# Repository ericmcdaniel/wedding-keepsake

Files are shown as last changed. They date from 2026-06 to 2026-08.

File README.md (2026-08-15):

# Wedding Keychain Keepsake

This is the full schematic, design, plans, and source code for the interactive RGB LED keepsake gadget from Eric and Stephie's wedding on Saturday August 15th 2026. These PCBs are attached to a keychain and were distributed to guests as keepsake party favors. The keychain displays a bright grid of LED lights and features simple animations and games.

# Modes

When powered on, the keychain begins in either one of two modes: Animation mode and Game mode. Press and Hold the button for one second to switch between Animation and Game modes.

### Animation Mode

The keychain displays an animation from the selection below. Single-press the button to cycle between the following animations.
* Tunnel
* Swipe
* Rainbow
* American Flag
* Candle

### Game Mode

As of this writing, the keychain only offers one game named *Dodge*. Dodge is a space-themed endless runner arcade survival game. You are piloting a space shuttle, traveling through the solar system. You encouter space debris, and must evade them before they collide into you.

Single-press the button to steer your rocket in the opposite direction to dodge obstacles. Survive as long as you can, even as you accelerate through the debris at progressively faster rates.

# Bill of Materials

* 32 acrylic-diffused RGB LEDs, arranged in an 8x4 matrix.
* ~~A MEMS microphone and op-amp for simple audio sampling (no FFT).~~
  * This idea was included in the design and was manufactured. The idea was to create additional audio-reactive (and interactive) modes like animations for decibel and music analyzers, but development time exceeded my delivery timeline. This will be revisited later in future updates.
* Animations can be cycled and games that can be played using the single tactile push button.
* Controlled by the AVR-based ATtiny1614 manufactured by *Microchip Technology*.
* Powered by a 24mm x 5mm CR2450 coin cell battery.
* On an 80mm x 30mm PCB with a D-hook clasp and snake keychain.
* Placed inside a custom-made sled enclosure with snap-fit sliding lid.

# Design

## 3D Rendering
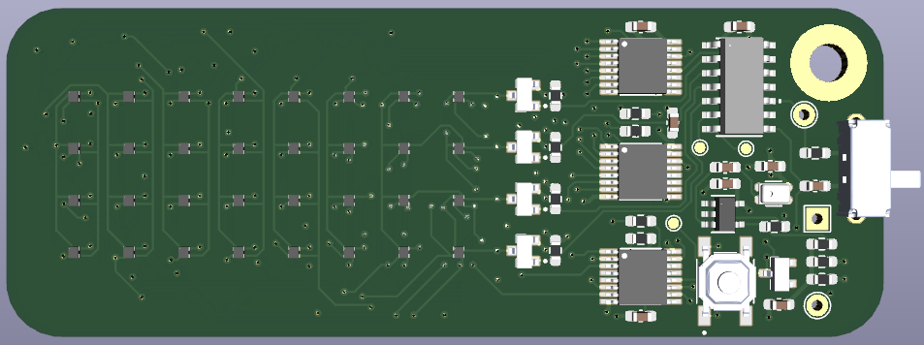
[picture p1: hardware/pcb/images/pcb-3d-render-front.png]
Front side of the PCB

<p align="center"><i>Front side of the PCB</i></p>

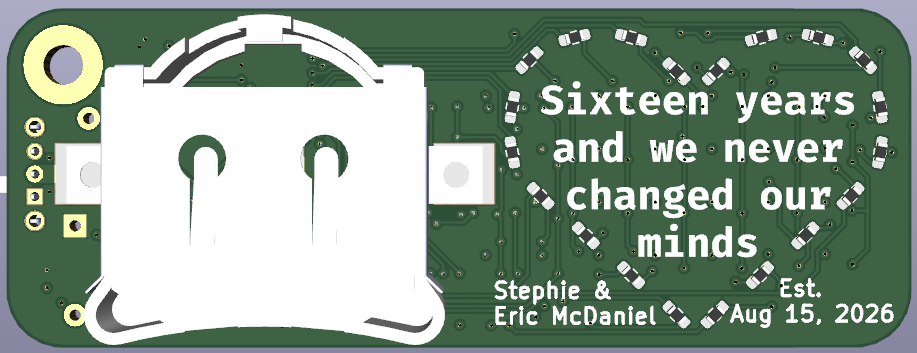
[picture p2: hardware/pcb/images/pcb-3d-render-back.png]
Back side of the PCB

<p align="center"><i>Back side of the PCB</i></p>

## Electrical Schematic
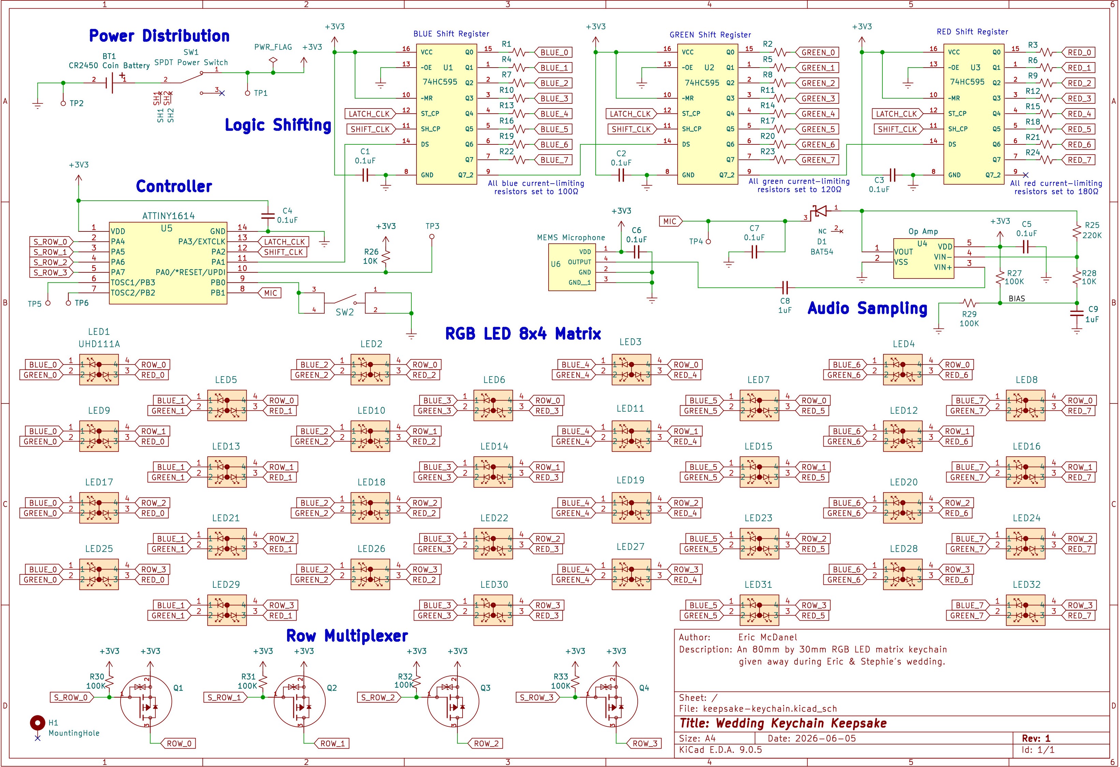
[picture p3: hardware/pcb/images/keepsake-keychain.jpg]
Electrical Schematic


## PCB Layout
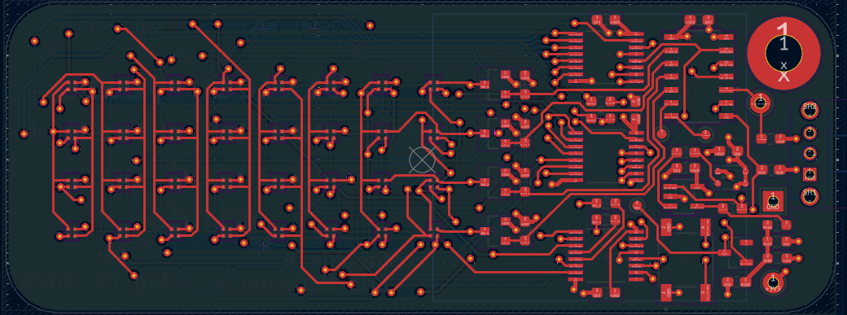
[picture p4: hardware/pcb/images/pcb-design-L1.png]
Layer 1 of PCB Design

<p align="center"><i>Layer 1 of the PCB (signals/components)</i></p>

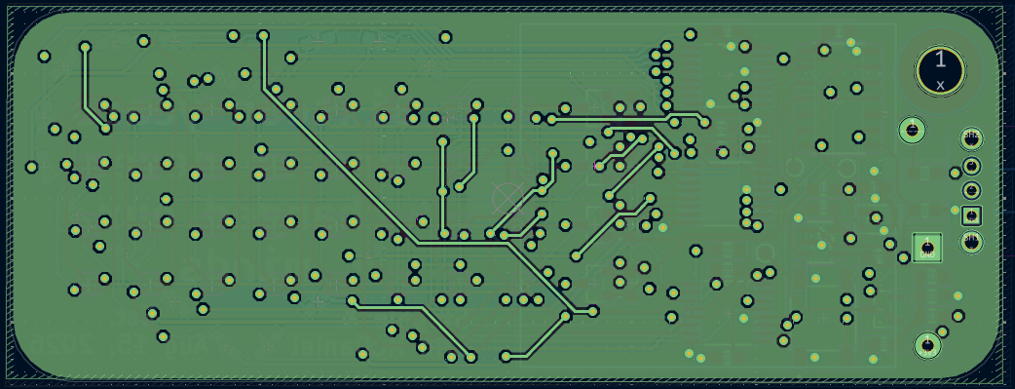
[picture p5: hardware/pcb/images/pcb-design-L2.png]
Layer 2 of PCB Design

<p align="center"><i>Layer 2 of the PCB (GND)</i><p>

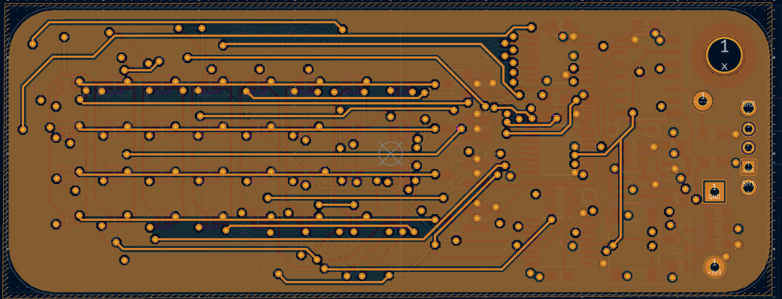
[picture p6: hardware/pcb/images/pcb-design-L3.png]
Layer 3 of PCB Design

<p align="center"><i>Layer 3 of the PCB (3V3 copper pour)</i><p>

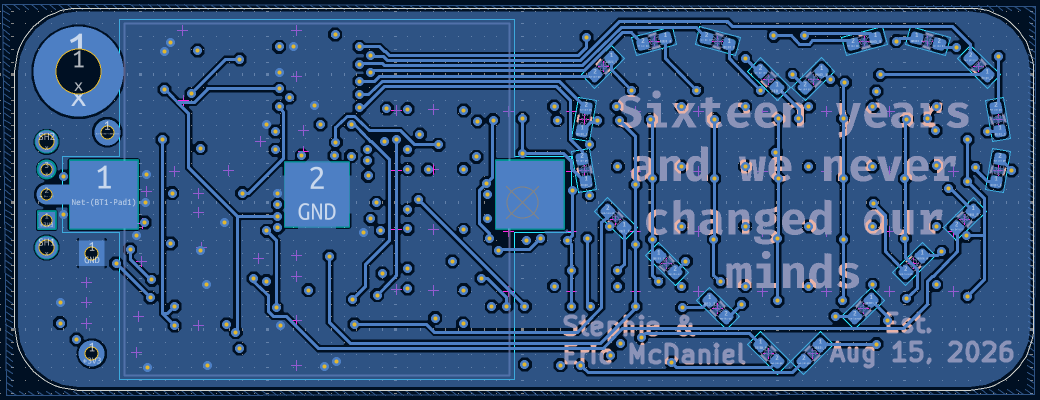
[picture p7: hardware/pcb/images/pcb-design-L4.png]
Layer 4 of PCB Design

<p align="center"><i>Layer 4 of the PCB (Additional signals/components)</i><p>

# Details

### Architecture and Engine

This repository was built using the toolkits provided by PlatformIO. It is based on the Arduino framework, though quite minimally. An RTOS is not used, fairly bare metal in terms of architecture. To keep things as efficient as possible, abstractions that Arduino provides like `digitalWrite()` were replaced with direct register manipulations, especially duirng hot execution paths. Most notably it is used during the LED rendering logic, which renders each row sequentially for 50 microseconds, creating a multiplexed effect on the display, as if all the LEDs were on simutaneously. The main reason that the Arduino framework is still used is because of the timers.

Internally, this repo was built on top of the custom game engine used in the [LumenLab](https://github.com/ericmcdaniel/lumenlab), with a handful of adaptations. This includes the platform-level core services, the engine, and general architecture from the LumenLab. This repo implements multiplexing manually, so libraries like FastLED used in the LumenLab could not be used. The keychain runs the main game loop at 60 Hz. Between each frame, the engine multiplexes each row at a frequency of 20 kHz (50 microseconds). Between each row rendering, three shift registers designated to the red, green, and blue channels take in a serial stream of bits to indicate if the respective color's LED should be on. If it's signal LOW, the LED turns on, and if signal HIGH then off. (this is in reverse because the MOSFETS are active HIGH).

Pulse-width modulation (PWM) is needed to dim the three primary colors, allowing for any arbitrary color can be made via blending. This was implemented using [bit-angle modulation (BAM)](https://www.desertember.com/posts/bit-angle-modulation.html) to determine the duty cycle. That was a headache, almost literally, because given large time values, the PWM's duty cycle would be so spread your eyes would noticably see the flicker. The color depth was reduced to 6-bit. The flicker isn't fully removed, but it's significantly better. Brightness and gamma correction was implemented, but disabled because adjustmenets is needed (again, mostly due to the noticable PWM flicker).

### Audio profiling (not implemented)

A MEMS microphone and amplifier was a part of the keychain's goal and is still a part of the design and schematic. The idea was realistic to implement, but was bound by an ambitious timeline, so I had to pause development that for now. The microphone still remains on the PCB since they were already manufactured (center-right). This gives me the opportunity to simply suspend working on the audio-reactive features rather than cancel entirely.

The idea for this keychain was to include audio reactivity, which would complement the already interactive animations. Running a full spectrum analyzer was not possible given the microcontroller selected, power constraints, and technical limitations like the inability to timely perform computationally heavy Fast-Fourier Transformations (FFT). So to be clear, it is too low-powered/low-budget to record conversation. Instead, the device was going to sample decibel levels in real time and display a sound-reactive bar, like the EQ on a stereo system. Another idea I had for the built-in microphone was to make the devices react to the wedding reception music live in real time. Between songs, I could have my computer play a swift, 20+ kHz logic signal at the before every song. This high-frequency chirp wouldn't be heard by humans, but detected by this keychain. It would then decode the message, and play an animation or color theme dynamically, as if it's listening to the music and dancing along.

These were two ideas that have artifacts on the board, but were not implemented.

# Development

### Software

The keychain is programmable using the UPDI protocol, which is the newer version of AVR's ISP and JTAG programming. The UPDI (PA0, pin 10) is exposed on a THT test pad, along with 3V3 and GND. To program the device, you need a $7 module called the UPDI Friend - USB Serial UPDI Programmer from [Adafruit](https://www.adafruit.com/product/5879) or [Digikey](https://www.digikey.com/en/products/detail/adafruit-industries-llc/5879/22596413). Releases are provided every PR and can be flashed directly. I'll write instructions to directly flash the device later (hopefully), and possibly even dockerize it for simplicity. Until then, the easiest way to update is to install the PlatformIO toolkit, compile this repo locally, and flash using the *PlatformIO: Upload (Release)* build script included.

In addition to the UPDI pin, PB2 (pin 7) and PB3 (pin 6) are mapped to TX and RX respectively. Because they were unused, these pins are exposed as SMD test pads. This allows you to probe TX (PB2) to read the serial logs, if you compiled the debug version.

### Hardware

The PCB design files were made using KiCad 9.0.5. The board layout was optimized for the manufacturing capabilities of [PCBWay](https://www.pcbway.com/). Before you start writing me hate mail, know that I'm aware of the issues, such as the lack of ESD protection and reverse polarity protection. Perhaps a future revision can include these, but I have no such plans.

The enclosure was made using FreeCAD 1.1.0. They also suck, but I tried. The models were also exported as .3mf files, and were optimized for immediate FDM printing, particularly the Bambu Labs A1 Combo. Feel free to adjust as needed for your machine. The model includes a sled enclosure which retains the PCB using four friction fit ribs. A lid is attached by sliding it along the guide rails from left to right. A snap-fit latch locks the lid in place, preventing it from falling off. I printed this using Bambu Lab's PLA Basic, however given the variance between 3D printers, brands, filament, and other conditions, your mileage may vary.

## AI Disclaimer

AI was consulted as a research and discovery analysis tool. I asked it general design, architecture, and best practices questions, especially during the board bring-up stage. I don't have a professional background in electrical engineering (is YouTube University accredited?), so I used it as a an informational resource. 

*Generative* AI, however, was **not** used to author code. Call me a luddite, but this is out of priniciple. Software engineering is an art as it is a science. Cheers to all the other crazies out there!

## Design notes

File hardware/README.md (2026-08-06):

# Enclosure

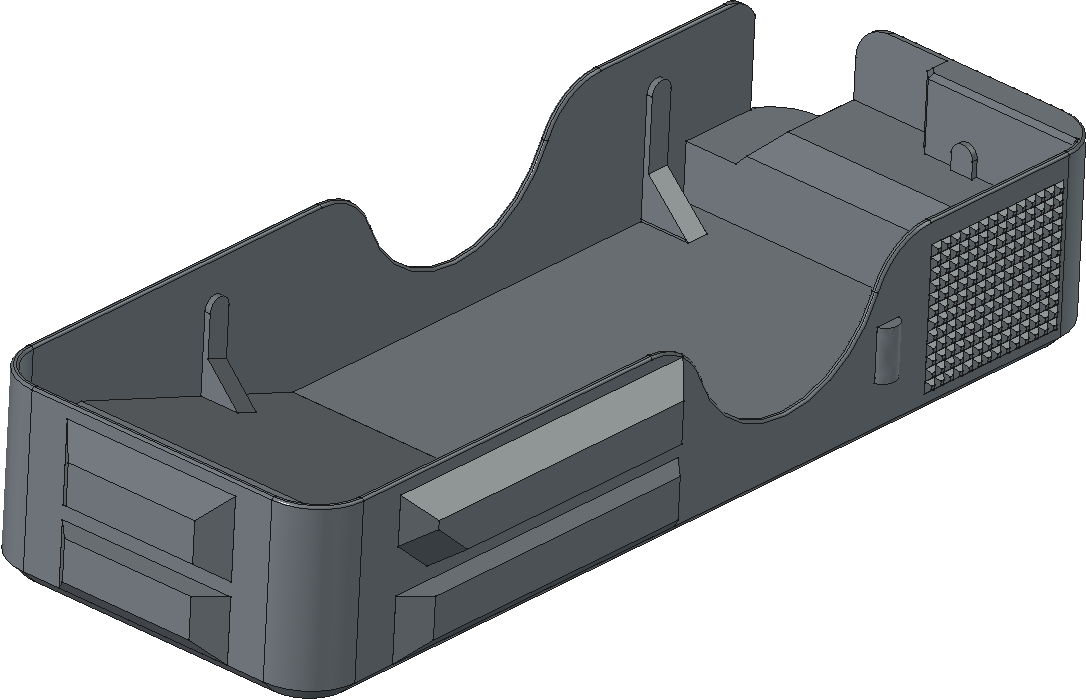
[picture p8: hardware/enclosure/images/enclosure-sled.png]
Enclosure without lid

<p align="center"><i>Enclosure Sled without the Lid</i></p>

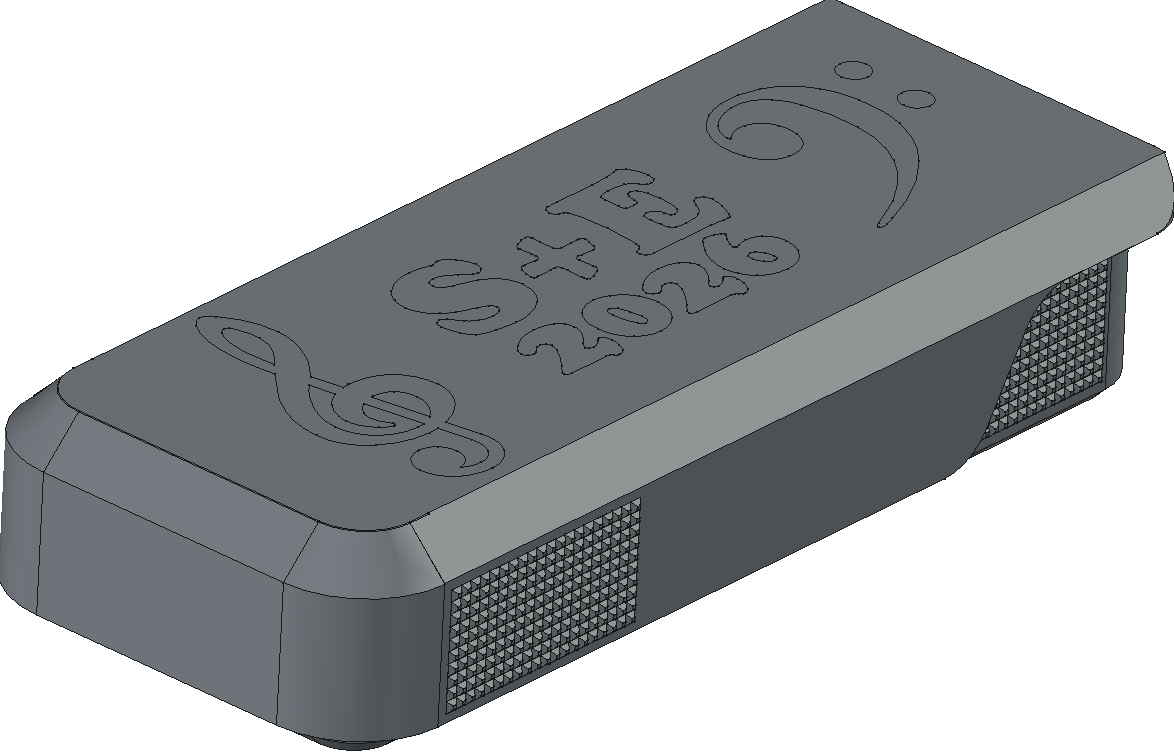
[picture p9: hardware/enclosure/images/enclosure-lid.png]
Enclosure with the lid

<p align="center"><i>Enclosure with the Lid</i></p>

# PCB 3D Rendering
Front side of the PCB
<p align="center"><i>Front side of the PCB</i></p>

Back side of the PCB
<p align="center"><i>Back side of the PCB</i></p>

# Electrical Schematic
Electrical Schematic

# PCB Layout
Layer 1 of PCB Design
<p align="center"><i>Layer 1 of the PCB (signals/components)</i></p>

Layer 2 of PCB Design
<p align="center"><i>Layer 2 of the PCB (GND)</i><p>

Layer 3 of PCB Design
<p align="center"><i>Layer 3 of the PCB (3V3 copper pour)</i><p>

Layer 4 of PCB Design
<p align="center"><i>Layer 4 of the PCB (Additional signals/components)</i><p>

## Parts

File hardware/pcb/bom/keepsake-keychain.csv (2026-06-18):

Reference | Qty | Value | DNP | Exclude from BOM | Footprint | Digi-Key_PN | MPN | Manufacturer
BT1 | 1 | CR2450 Coin Battery | DNP | Excluded from BOM | 0_Coin_Battery_Holder:battery-holder | BHX1-2450-SM-ND | BHX1-2450-SM | MPD (Memory Protection Devices)
C1,C2,C3,C4,C5,C6,C7 | 7 | 0.1uF |  |  | Capacitor_SMD:C_0603_1608Metric_Pad1.08x0.95mm_HandSolder | 4713-GMC10X7R104K25NTCT-ND | GMC10X7R104K25NT | Cal-Chip Electronics, Inc.
C8,C9 | 2 | 1uF |  |  | Capacitor_SMD:C_0603_1608Metric_Pad1.08x0.95mm_HandSolder | 1292-0603B105K250CT-ND | 0603B105K250CT | Walsin Technology Corporation
D1 | 1 | BAT54 |  |  | 0_Schottky_Diode:SOT95P240X120-3N | 4878-BAT54CT-ND | BAT54 | Diotec Semiconductor
H1 | 1 | MountingHole | DNP | Excluded from BOM | MountingHole:MountingHole_3.5mm_Pad_TopBottom
LED1,LED2,LED3,LED4,LED5,LED6,LED7,LED8,LED9,LED10,LED11,LED12,LED13,LED14,LED15,LED16,LED17,LED18,LED19,LED20,LED21,LED22,LED23,LED24,LED25,LED26,LED27,LED28,LED29,LED30,LED31,LED32 | 32 | UHD111A |  |  | 0_RGB_LED:rgb-led | 90-UHD111A-FKA-C3K23E1L3VG5ZB3Z3-ND | UHD111A-FKA-C3K23E1L3VG5ZB3Z3 | Cree LED
Q1,Q2,Q3,Q4 | 4 | MMFTP4042K |  |  | 0_MOSFET:mosfet | 4878-MMFTP4042KCT-ND | MMFTP4042K | Diotec Semiconductor
R1,R4,R7,R10,R13,R16,R19,R22 | 8 | 100 |  |  | Resistor_SMD:R_0603_1608Metric_Pad0.98x0.95mm_HandSolder | 1292-WR06X101JTLCT-ND | WR06X101 JTL | Walsin Technology Corporation
R2,R5,R8,R11,R14,R17,R20,R23 | 8 | 120 |  |  | Resistor_SMD:R_0603_1608Metric_Pad0.98x0.95mm_HandSolder | RMCF0603JT120RCT-ND | RMCF0603JT120R | Stackpole Electronics Inc
R3,R6,R9,R12,R15,R18,R21,R24 | 8 | 180 |  |  | Resistor_SMD:R_0603_1608Metric_Pad0.98x0.95mm_HandSolder | RMCF0603JT180RCT-ND | RMCF0603JT180R | Stackpole Electronics Inc
R25 | 1 | 220K |  |  | Resistor_SMD:R_0603_1608Metric_Pad0.98x0.95mm_HandSolder | 1292-WR06X2203FTLCT-ND | WR06X2203FTL | Walsin Technology Corporation
R26,R28 | 2 | 10K |  |  | Resistor_SMD:R_0603_1608Metric_Pad0.98x0.95mm_HandSolder | 311-10.0KHRCT-ND | RC0603FR-0710KL | YAGEO
R27,R29,R30,R31,R32,R33 | 6 | 100K |  |  | Resistor_SMD:R_0603_1608Metric_Pad0.98x0.95mm_HandSolder | CR0603-JW-104ELFCT-ND | CR0603-JW-104ELF | Bourns Inc.
SW1 | 1 | SPDT Power Switch | DNP | Excluded from BOM | 0_SPDT_Switch:spdt-switch | 2223-SLW-835636-3A-RA-N-D-ND | SLW-835636-3A-RA-N-D | Same Sky (Formerly CUI Devices)
SW2 | 1 | PTS636 SK25J SMTR LFS | DNP | Excluded from BOM | 0_Tactile_Push_Button:SW_TS18-5-15-SL-160-SMT-TR | 2223-TS18-5-15-SL-160-SMT-TRCT-ND | TS18-5-15-SL-160-SMT-TR | Same Sky (Formerly CUI Devices)
TP1,TP3 | 2 | 5002 | DNP | Excluded from BOM | TestPoint:TestPoint_THTPad_D2.0mm_Drill1.0mm
TP2 | 1 | 5002 | DNP | Excluded from BOM | TestPoint:TestPoint_THTPad_2.0x2.0mm_Drill1.0mm
TP4,TP5,TP6 | 3 | 5002 | DNP | Excluded from BOM | TestPoint:TestPoint_Pad_D1.0mm
U1,U2,U3 | 3 | 74HC595 |  |  | 0_74HC595_Shift_Register:shift-register | 1727-3068-1-ND | 74HC595PW,118 | Nexperia USA Inc.
U4 | 1 | Op Amp |  |  | 0_Op_Amp:SOT-23-5_MC_MCH | MCP6001T-I/OTCT-ND | MCP6001T-I/OT | Microchip Technology
U5 | 1 | ATTINY1614 |  |  | 0_ATtiny1614:SOIC14_SL_MCH | ATTINY1614-SSF-ND | ATTINY1614-SSF | Microchip Technology
U6 | 1 | MEMS Microphone |  |  | 0_Microphone:MIC_3SM123C4T1QA | 5280-3SM123C4T1QACT-ND | 3SM123C4T1QA | 3S (Solid State System)

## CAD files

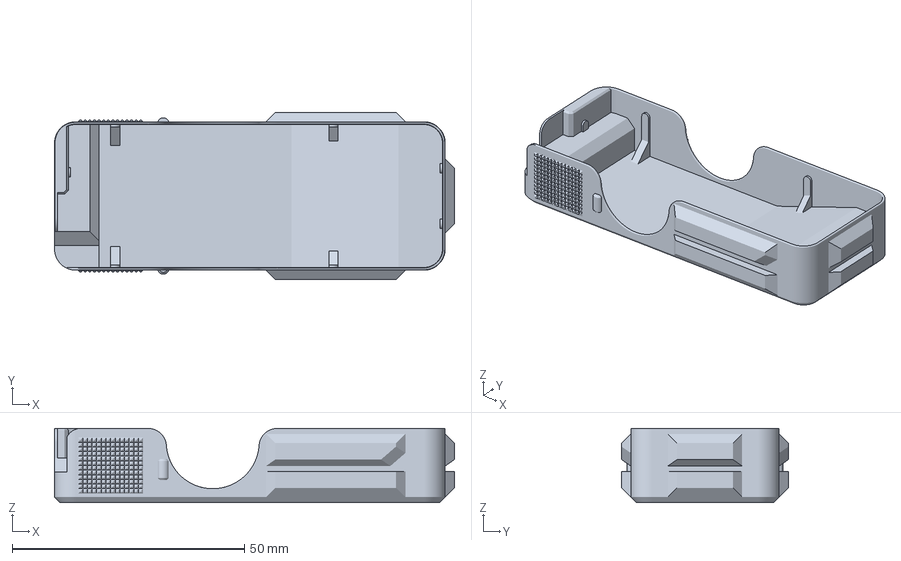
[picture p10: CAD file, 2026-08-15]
hardware/enclosure/wedding-keychain-enclosure.3mf
86.2 x 36.0 x 16.0 mm

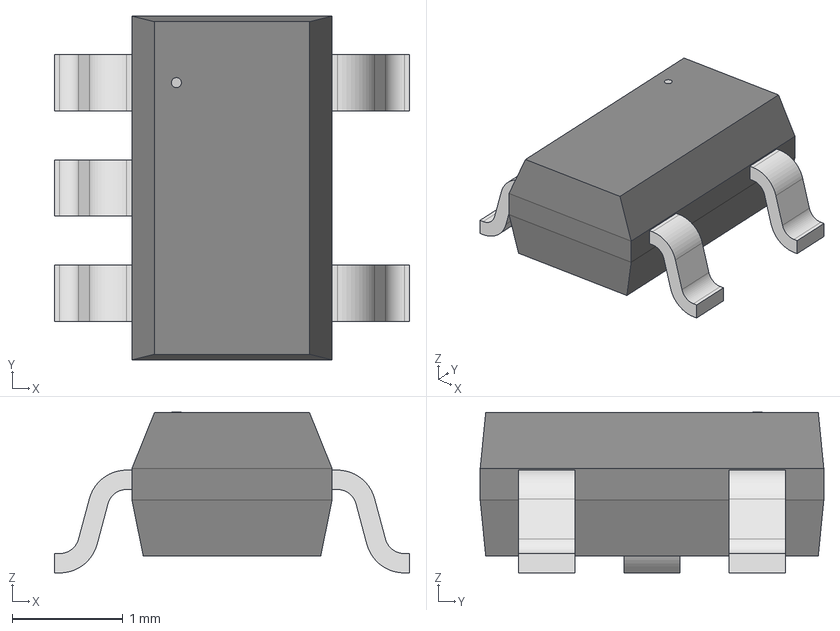
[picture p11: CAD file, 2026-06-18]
hardware/pcb/cad-models/op-amp.step
3.20 x 3.10 x 1.45 mm

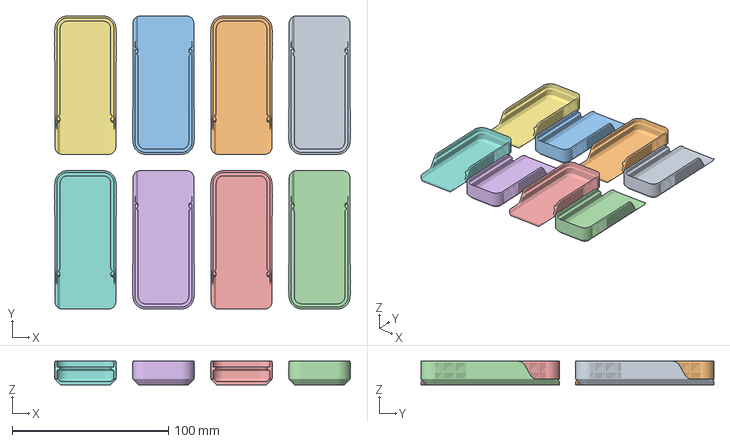
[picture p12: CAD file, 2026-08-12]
hardware/enclosure/wedding-keychain-lid.3mf
189.5 x 187.4 x 15.1 mm
wedding-keychain-lid x 8

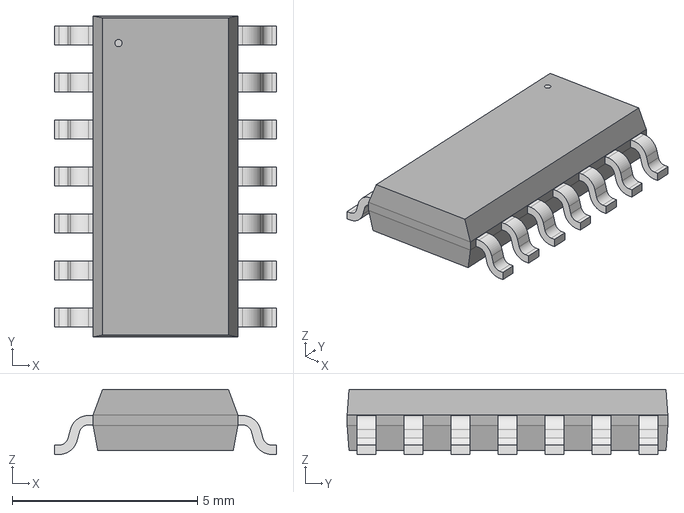
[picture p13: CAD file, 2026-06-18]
hardware/pcb/cad-models/attiny-1614.step
5.99 x 8.66 x 1.75 mm

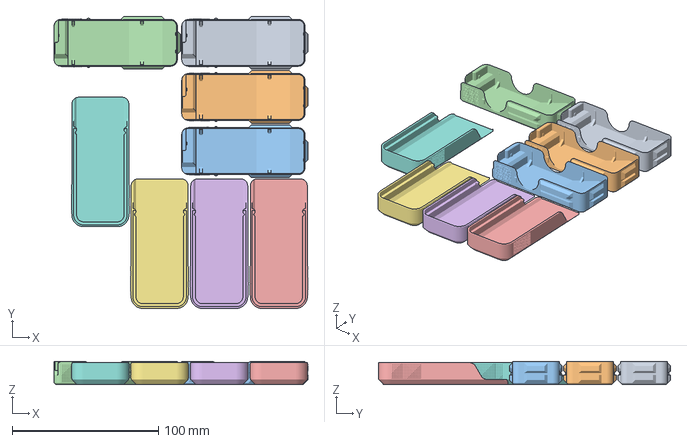
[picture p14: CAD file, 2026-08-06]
hardware/enclosure/wedding-keychain-combo.3mf
173.4 x 199.5 x 16.0 mm
wedding-keychain-lid x 4

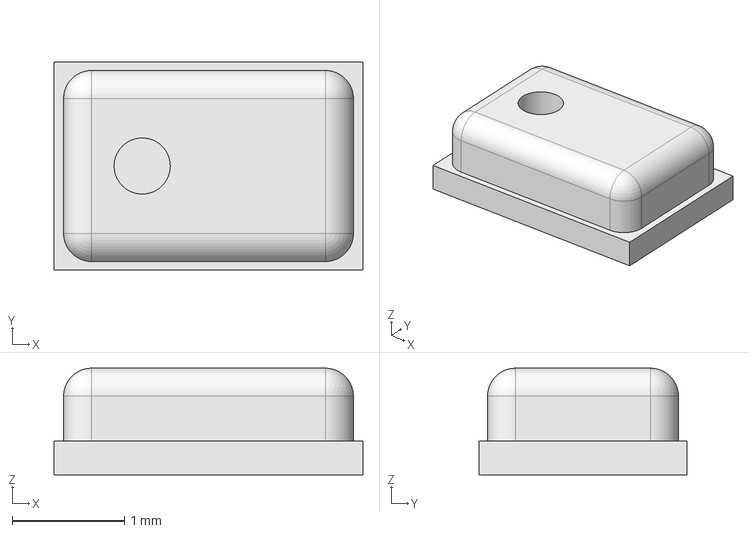
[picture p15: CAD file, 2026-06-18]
hardware/pcb/cad-models/microphone.step
2.75 x 1.85 x 0.95 mm

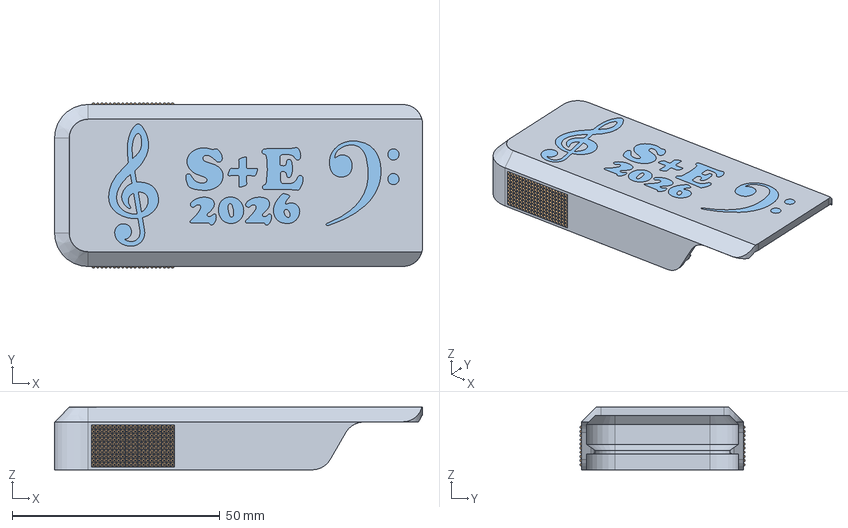
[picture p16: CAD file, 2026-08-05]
hardware/enclosure/wedding-keychain.FCStd
88.5 x 39.7 x 15.1 mm
lid
knurling
writing

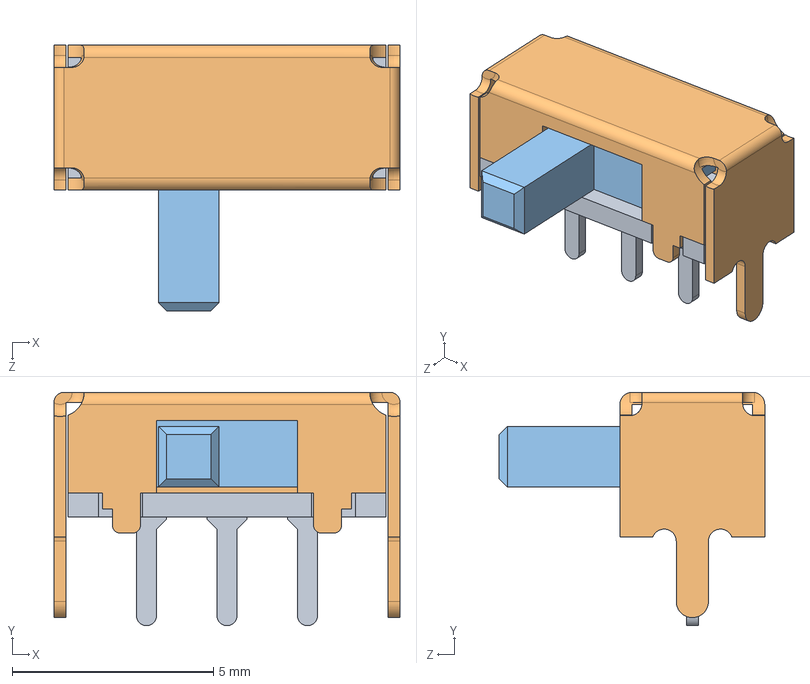
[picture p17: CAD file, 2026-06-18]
hardware/pcb/cad-models/spdt-switch.step
8.60 x 5.80 x 6.60 mm

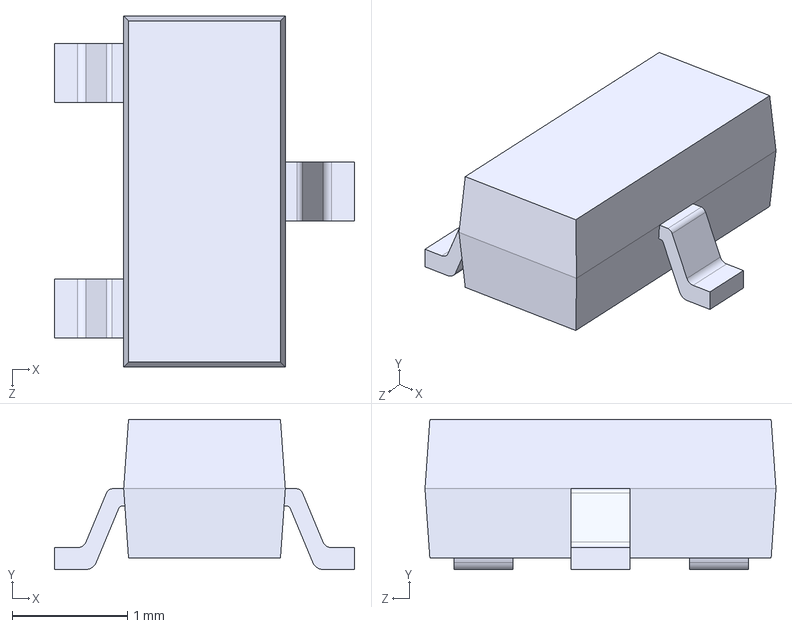
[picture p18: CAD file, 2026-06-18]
hardware/pcb/cad-models/mosfet.step
2.60 x 1.30 x 3.04 mm

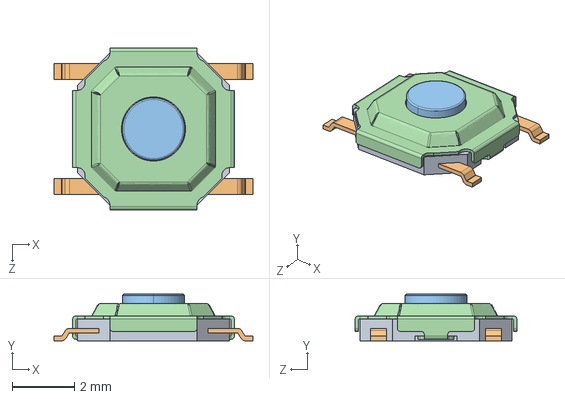
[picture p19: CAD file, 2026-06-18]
hardware/pcb/cad-models/tactile-push-button.step
6.40 x 1.50 x 5.20 mm

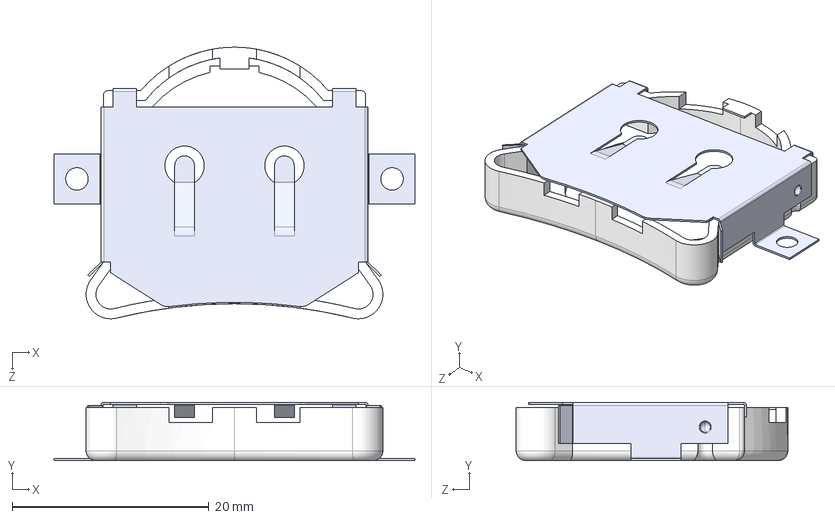
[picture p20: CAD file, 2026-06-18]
hardware/pcb/cad-models/coin-battery-holder.step
36.7 x 5.92 x 27.6 mm

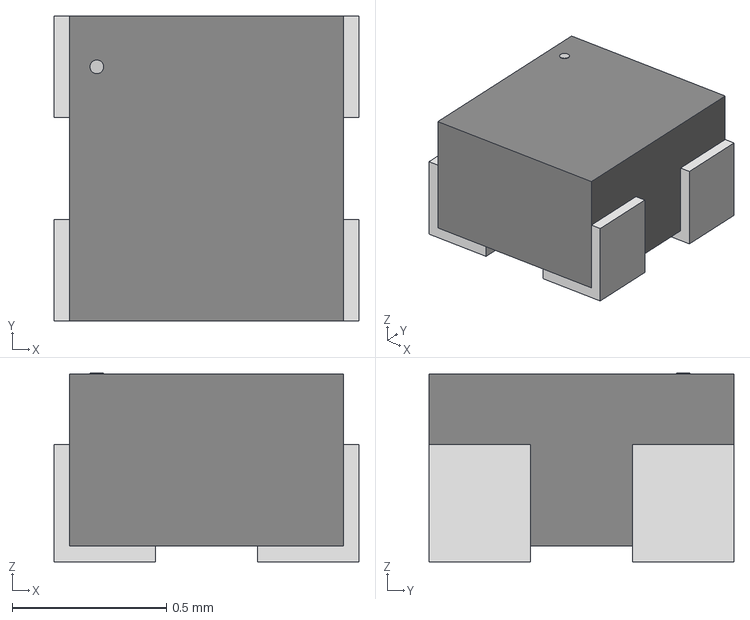
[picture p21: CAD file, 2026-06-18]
hardware/pcb/cad-models/rgb-led.step
0.99 x 0.99 x 0.612 mm

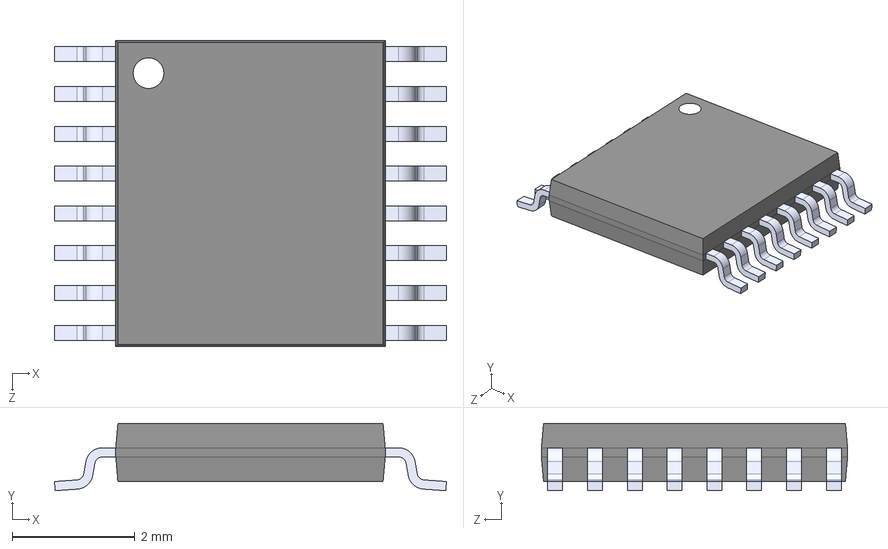
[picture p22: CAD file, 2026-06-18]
hardware/pcb/cad-models/74hc595.step
6.40 x 1.10 x 5.00 mm

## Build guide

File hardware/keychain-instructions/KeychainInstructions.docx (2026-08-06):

Stephie and Eric’s Wedding Keychain Keepsake

Thank you for celebrating our special day with us! It’s our pleasure to share this keepsake gadget with the people who have inspired, supported, and helped shape who we are today. This interactive, custom-made keychain displays a bright grid of LED lights and features simple animations and games.

Power Switch

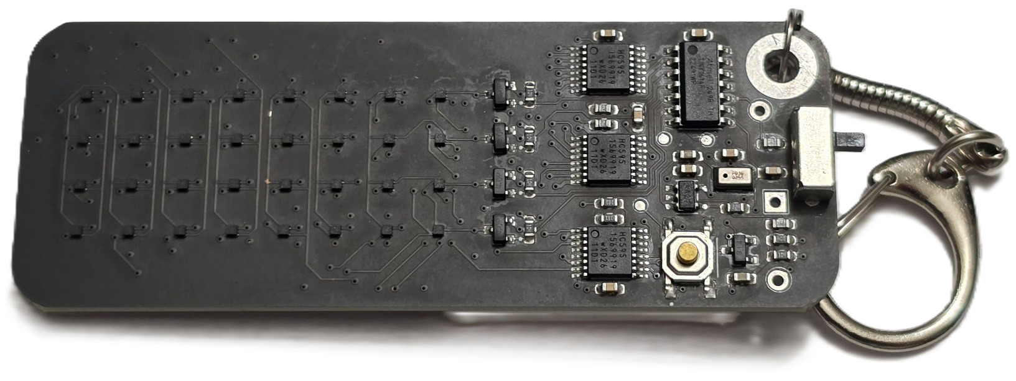
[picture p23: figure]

Tactile Push Button

8 x 4 LED Matrix

How to Start

Fully remove the keychain from its enclosure. Power it by sliding down the switch on the right side. The LED matrix will light up and start in either Animation mode or Game mode. You interact with the keychain using the tactile push button on the bottom right edge of the circuit board, using either single-presses or by holding the button down.

How to Use

Hold the button down to switch between modes.

Game Mode Dodge is an endless runner arcade survival game. You are a space shuttle traveling through the solar system, and you must evade space debris before it collides into you. Single-press the button to steer your rocket in the opposite direction to dodge obstacles. | | Animation Mode Single-press the button to cycle through the animations - Tunnel - Swipe - Rainbow - American Flag - Candle

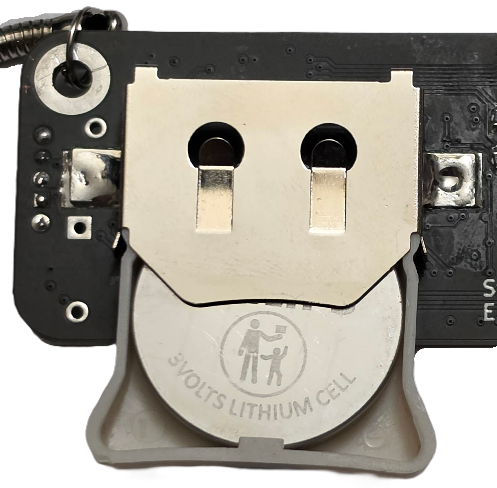
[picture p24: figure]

| Replacing the Battery This keychain is powered using a CR2450 battery. It is attached on a sled for easy removal. Take note of the orientation of the battery. Do NOT reverse the polarity. When replacing it, be sure to place the button’s belly (-) flat on the circuit board, as shown on the left.

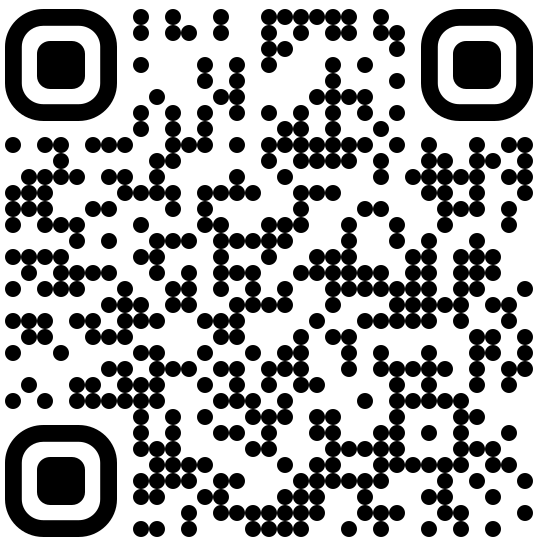
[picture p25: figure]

For the Nerds This entire project is free and open sauce. It includes all PCB design and CAD enclosure files configured for manufacture and FDM printing.

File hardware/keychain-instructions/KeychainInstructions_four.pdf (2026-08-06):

## Stephie and Eric’s Wedding Keychain Keepsake

Thank you for celebrating our special day with us! It’s our pleasure to share this keepsake gadget with the people who have inspired, supported, and helped shape who we are today. This interactive, custom-made keychain displays a bright grid of LED lights and features simple animations and games.

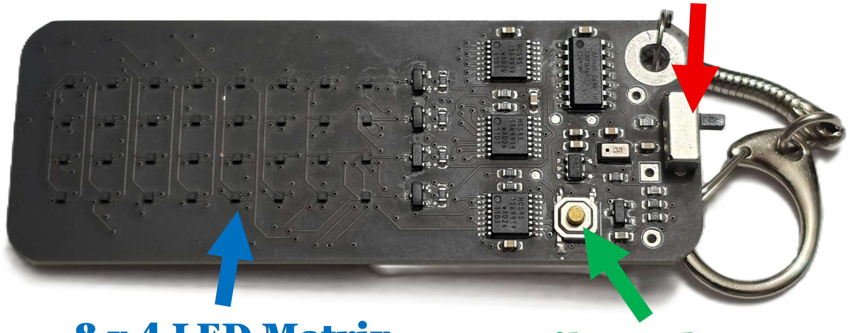
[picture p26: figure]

## How to Start

Fully remove the keychain from its enclosure. Power it by sliding down the switch on the right side. The LED matrix will light up and start in either Animation mode or Game mode. You interact with the keychain using the tactile push button on the bottom right edge of the circuit board, using either single-presses or by holding the button down.

### 8 x 4 LED Matrix Tactile Push Button

Power Switch

## Stephie and Eric’s Wedding Keychain Keepsake

Thank you for celebrating our special day with us! It’s our pleasure to share this keepsake gadget with the people who have inspired, supported, and helped shape who we are today. This interactive, custom-made keychain displays a bright grid of LED lights and features simple animations and games.

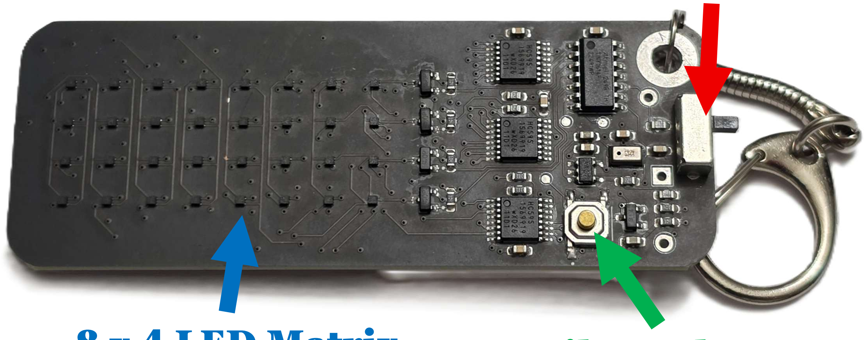
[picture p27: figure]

## How to Start

Fully remove the keychain from its enclosure. Power it by sliding down the switch on the right side. The LED matrix will light up and start in either Animation mode or Game mode. You interact with the keychain using the tactile push button on the bottom right edge of the circuit board, using either single-presses or by holding the button down.

### 8 x 4 LED Matrix Tactile Push Button

Power Switch

## Stephie and Eric’s Wedding Keychain Keepsake

Thank you for celebrating our special day with us! It’s our pleasure to share this keepsake gadget with the people who have inspired, supported, and helped shape who we are today. This interactive, custom-made keychain displays a bright grid of LED lights and features simple animations and games.

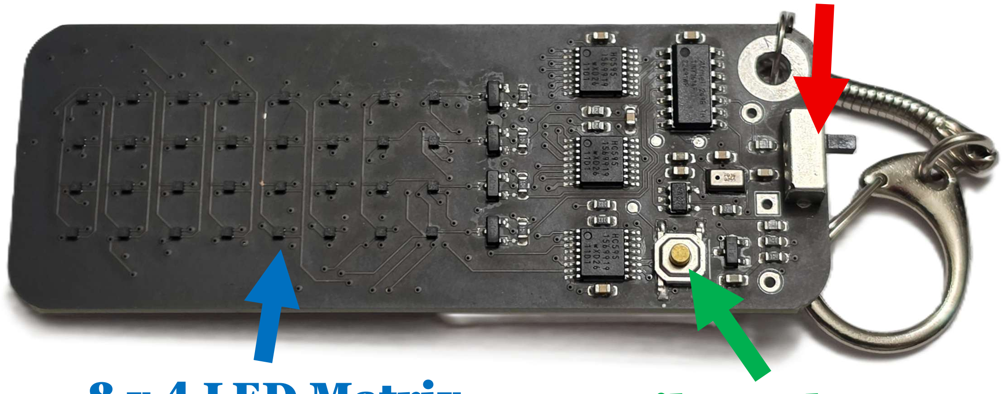
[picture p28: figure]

## How to Start

Fully remove the keychain from its enclosure. Power it by sliding down the switch on the right side. The LED matrix will light up and start in either Animation mode or Game mode. You interact with the keychain using the tactile push button on the bottom right edge of the circuit board, using either single-presses or by holding the button down.

### 8 x 4 LED Matrix Tactile Push Button

Power Switch

## Stephie and Eric’s Wedding Keychain Keepsake

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

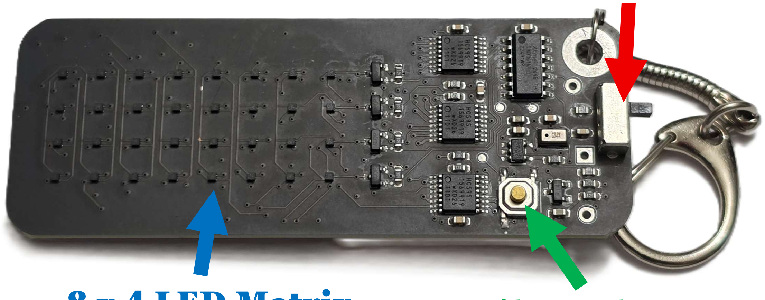
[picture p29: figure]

## How to Start

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

### 8 x 4 LED Matrix Tactile Push Button

Power Switch

## How to Use

Hold the button down to switch between modes. Game Mode Dodge is an endless runner arcade

survival game. You are a space shuttle
traveling through the solar system, and you must evade space debris before it collides into you. Single-press the button to steer your rocket in the opposite direction to dodge obstacles.

Animation Mode Single-press the button to

cycle through the animations Tunnel Swipe Rainbow

- American Flag Candle

## Replacing the Battery

This keychain is powered using a CR2450 battery. It is attached on a sled for easy removal. Take note of the orientation of the battery. Do NOT reverse the polarity. When replacing it, be sure to place the button’s belly (-) flat on the circuit board, as shown on the left. For the Nerds

This entire project is free and open
sauce. It includes all PCB design and CAD enclosure files configured for manufacture and FDM printing.

## How to Use

Hold the button down to switch between modes. Game Mode Dodge is an endless runner arcade

survival game. You are a space shuttle
traveling through the solar system, and you must evade space debris before it collides into you. Single-press the button to steer your rocket in the opposite direction to dodge obstacles.

Animation Mode Single-press the button to

cycle through the animations Tunnel Swipe Rainbow

- American Flag Candle

## Replacing the Battery

This keychain is powered using a CR2450 battery. It is attached on a sled for easy removal. Take note of the orientation of the battery. Do NOT reverse the polarity. When replacing it, be sure to place the button’s belly (-) flat on the circuit board, as shown on the left. For the Nerds

This entire project is free and open
sauce. It includes all PCB design and CAD enclosure files configured for manufacture and FDM printing. How to Use

Hold the button down to switch between modes. Game Mode Dodge is an endless runner arcade

survival game. You are a space shuttle
traveling through the solar system, and you must evade space debris before it collides into you. Single-press the button to steer your rocket in the opposite direction to dodge obstacles.

Animation Mode Single-press the button to

cycle through the animations Tunnel Swipe Rainbow

- American Flag Candle

## Replacing the Battery

This keychain is powered using a CR2450 battery. It is attached on a sled for easy removal. Take note of the orientation of the battery. Do NOT reverse the polarity. When replacing it, be sure to place the button’s belly (-) flat on the circuit board, as shown on the left. For the Nerds

This entire project is free and open
sauce. It includes all PCB design and CAD enclosure files configured for manufacture and FDM printing.

## How to Use

Hold the button down to switch between modes. Game Mode Dodge is an endless runner arcade

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

Animation Mode Single-press the button to

cycle through the animations Tunnel Swipe Rainbow

- American Flag Candle

## Replacing the Battery

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

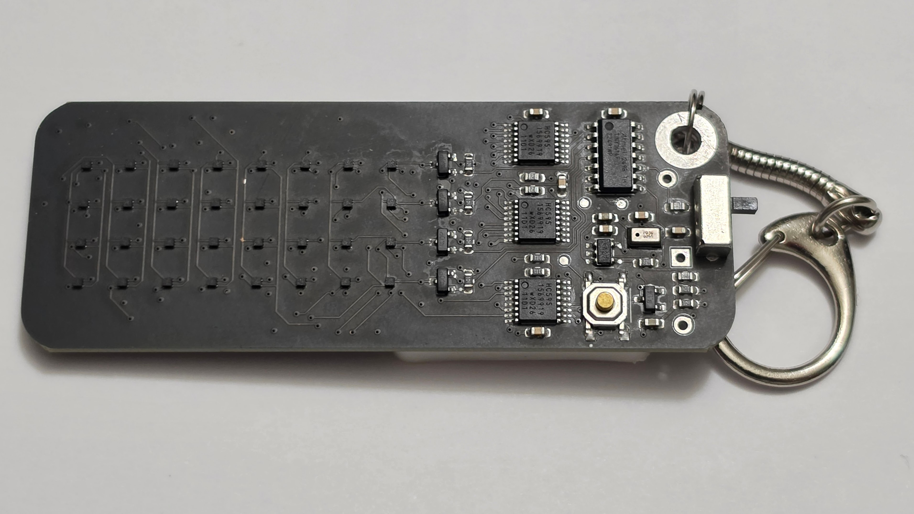
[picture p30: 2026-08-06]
hardware/keychain-instructions/20260804_213238.jpg

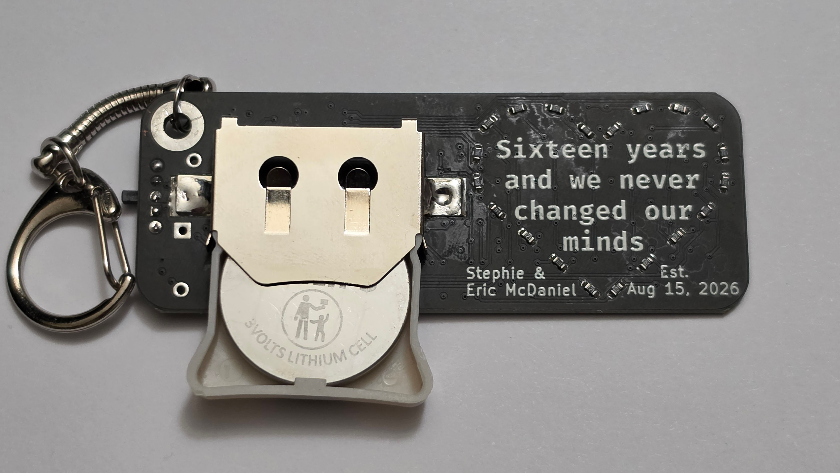
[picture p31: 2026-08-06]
hardware/keychain-instructions/20260805_182131.jpg

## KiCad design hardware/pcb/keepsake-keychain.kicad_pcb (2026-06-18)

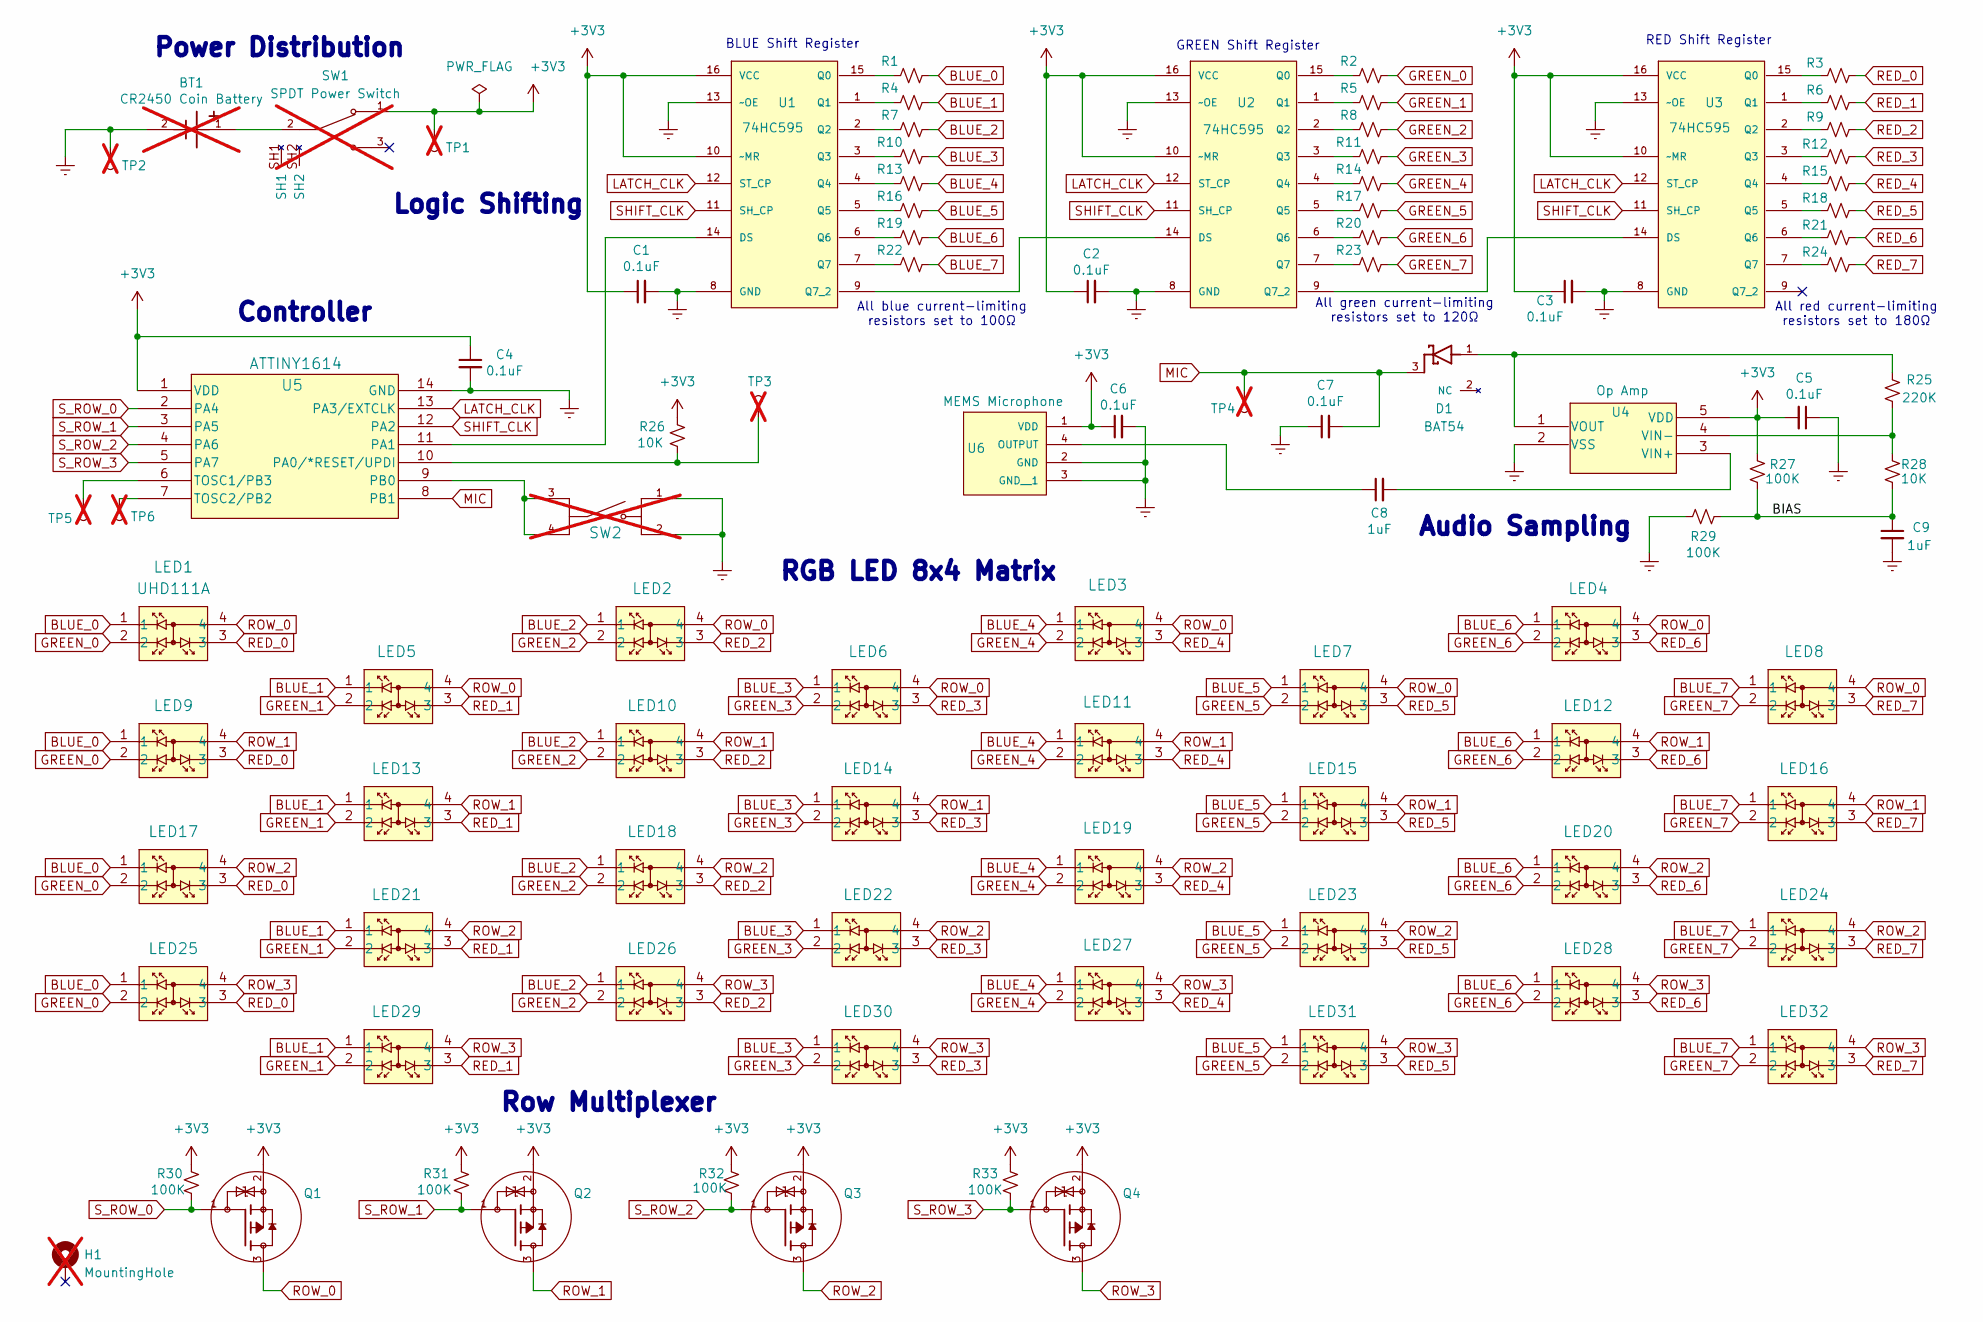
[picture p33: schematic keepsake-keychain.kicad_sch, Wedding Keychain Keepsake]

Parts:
BT1: CR2450 Coin Battery; battery-holder; PARTREV H; Digi-Key_PN BHX1-2450-SM-ND; not fitted
C1, C2, C3, C4, C5, C6, C7: 0.1uF; C_0603_1608Metric_Pad1.08x0.95mm_HandSolder; MPN GMC10X7R104K25NT; Digi-Key_PN 4713-GMC10X7R104K25NTCT-ND
C8, C9: 1uF; C_0603_1608Metric_Pad1.08x0.95mm_HandSolder; MPN 0603B105K250CT; Digi-Key_PN 1292-0603B105K250CT-ND
D1: BAT54; SOT95P240X120-3N; PARTREV 2025-04-24; Digi-Key_PN 4878-BAT54CT-ND
H1: MountingHole; MountingHole_3.5mm_Pad_TopBottom; not fitted
LED1, LED2, LED3, LED4, LED5, LED6, LED7, LED8, LED9, LED10, LED11, LED12, LED13, LED14, LED15, LED16, LED17, LED18, LED19, LED20, LED21, LED22, LED23, LED24, LED25, LED26, LED27, LED28, LED29, LED30, LED31, LED32: UHD111A; rgb-led; MPN UHD111A-FKA-C3K23E1L3VG5ZB3Z3; Digi-Key_PN 90-UHD111A-FKA-C3K23E1L3VG5ZB3Z3-ND
Q1, Q2, Q3, Q4: MMFTP4042K; mosfet; PARTREV 2024-05-07; Digi-Key_PN 4878-MMFTP4042KCT-ND
R1, R4, R7, R10, R13, R16, R19, R22: 100; R_0603_1608Metric_Pad0.98x0.95mm_HandSolder; MPN WR06X101 JTL; Digi-Key_PN 1292-WR06X101JTLCT-ND
R2, R5, R8, R11, R14, R17, R20, R23: 120; R_0603_1608Metric_Pad0.98x0.95mm_HandSolder; MPN RMCF0603JT120R; Digi-Key_PN RMCF0603JT120RCT-ND
R3, R6, R9, R12, R15, R18, R21, R24: 180; R_0603_1608Metric_Pad0.98x0.95mm_HandSolder; MPN RMCF0603JT180R; Digi-Key_PN RMCF0603JT180RCT-ND
R25: 220K; R_0603_1608Metric_Pad0.98x0.95mm_HandSolder; MPN WR06X2203FTL; Digi-Key_PN 1292-WR06X2203FTLCT-ND
R26, R28: 10K; R_0603_1608Metric_Pad0.98x0.95mm_HandSolder; MPN RC0603FR-0710KL; Digi-Key_PN 311-10.0KHRCT-ND
R27, R29, R30, R31, R32, R33: 100K; R_0603_1608Metric_Pad0.98x0.95mm_HandSolder; MPN CR0603-JW-104ELF; Digi-Key_PN CR0603-JW-104ELFCT-ND
SW1: SPDT Power Switch; spdt-switch; PARTREV 1.01; Digi-Key_PN 2223-SLW-835636-3A-RA-N-D-ND; not fitted
SW2: PTS636 SK25J SMTR LFS; SW_TS18-5-15-SL-160-SMT-TR; PARTREV 1.02; Digi-Key_PN 2223-TS18-5-15-SL-160-SMT-TRCT-ND; not fitted
TP1, TP3: 5002; TestPoint_THTPad_D2.0mm_Drill1.0mm; not fitted
TP2: 5002; TestPoint_THTPad_2.0x2.0mm_Drill1.0mm; not fitted
TP4, TP5, TP6: 5002; TestPoint_Pad_D1.0mm; not fitted
U1, U2, U3: 74HC595; shift-register; MPN 74HC595PW,118; Digi-Key_PN 1727-3068-1-ND
U4: Op Amp; SOT-23-5_MC_MCH; MPN MCP6001T-I/OT; Digi-Key_PN MCP6001T-I/OTCT-ND
U5: ATTINY1614; SOIC14_SL_MCH; MPN ATTINY1614-SSF; Digi-Key_PN ATTINY1614-SSF-ND
U6: MEMS Microphone; MIC_3SM123C4T1QA; PARTREV 1.4; Digi-Key_PN 5280-3SM123C4T1QACT-ND

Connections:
+3V3: C1.1, C2.1, C3.1, C4.1, C5.2, C6.1, Q1.2, Q2.2, Q3.2, Q4.2, R26.2, R27.1, R30.2, R31.2, R32.2, R33.2, SW1.1, TP1.1, U1.10 (~MR), U1.16 (VCC), U2.10 (~MR), U2.16 (VCC), U3.10 (~MR), U3.16 (VCC), U4.5 (VDD), U5.1 (VDD), U6.1 (VDD)
/BIAS: C9.1, R27.2, R28.2, R29.1
BLUE_0: LED1.1, LED9.1, LED17.1, LED25.1, R1.1
BLUE_1: LED5.1, LED13.1, LED21.1, LED29.1, R4.1
BLUE_2: LED2.1, LED10.1, LED18.1, LED26.1, R7.1
BLUE_3: LED6.1, LED14.1, LED22.1, LED30.1, R10.1
BLUE_4: LED3.1, LED11.1, LED19.1, LED27.1, R13.1
BLUE_5: LED7.1, LED15.1, LED23.1, LED31.1, R16.1
BLUE_6: LED4.1, LED12.1, LED20.1, LED28.1, R19.1
BLUE_7: LED8.1, LED16.1, LED24.1, LED32.1, R22.1
GND: BT1.2, C1.2, C2.2, C3.2, C4.2, C5.1, C6.2, C7.1, C9.2, R29.2, SW2.1, SW2.2, TP2.1, U1.8 (GND), U1.13 (~OE), U2.8 (GND), U2.13 (~OE), U3.8 (GND), U3.13 (~OE), U4.2 (VSS), U5.14 (GND), U6.2 (GND), U6.3 (GND__1)
GREEN_0: LED1.2, LED9.2, LED17.2, LED25.2, R2.1
GREEN_1: LED5.2, LED13.2, LED21.2, LED29.2, R5.1
GREEN_2: LED2.2, LED10.2, LED18.2, LED26.2, R8.1
GREEN_3: LED6.2, LED14.2, LED22.2, LED30.2, R11.1
GREEN_4: LED3.2, LED11.2, LED19.2, LED27.2, R14.1
GREEN_5: LED7.2, LED15.2, LED23.2, LED31.2, R17.1
GREEN_6: LED4.2, LED12.2, LED20.2, LED28.2, R20.1
GREEN_7: LED8.2, LED16.2, LED24.2, LED32.2, R23.1
LATCH_CLK: U1.12 (ST_CP), U2.12 (ST_CP), U3.12 (ST_CP), U5.13 (PA3/EXTCLK)
MIC: C7.2, D1.3, TP4.1, U5.8 (PB1)
unnamed: BT1.1, SW1.2
unnamed: U1.14 (DS), U5.11 (PA1)
unnamed: R1.2, U1.15 (Q0)
unnamed: R4.2, U1.1 (Q1)
unnamed: R7.2, U1.2 (Q2)
unnamed: R10.2, U1.3 (Q3)
unnamed: R13.2, U1.4 (Q4)
unnamed: R16.2, U1.5 (Q5)
unnamed: R19.2, U1.6 (Q6)
unnamed: R22.2, U1.7 (Q7)
unnamed: U1.9 (Q7_2), U2.14 (DS)
unnamed: R2.2, U2.15 (Q0)
unnamed: R5.2, U2.1 (Q1)
unnamed: R8.2, U2.2 (Q2)
unnamed: R11.2, U2.3 (Q3)
unnamed: R14.2, U2.4 (Q4)
unnamed: R17.2, U2.5 (Q5)
unnamed: R20.2, U2.6 (Q6)
unnamed: R23.2, U2.7 (Q7)
unnamed: U2.9 (Q7_2), U3.14 (DS)
unnamed: R3.2, U3.15 (Q0)
unnamed: R6.2, U3.1 (Q1)
unnamed: R9.2, U3.2 (Q2)
unnamed: R12.2, U3.3 (Q3)
unnamed: R15.2, U3.4 (Q4)
unnamed: R18.2, U3.5 (Q5)
unnamed: R21.2, U3.6 (Q6)
unnamed: R24.2, U3.7 (Q7)
unnamed: C8.2, U4.3 (VIN+)
unnamed: R25.2, R28.1, U4.4 (VIN-)
unnamed: D1.1, R25.1, U4.1 (VOUT)
unnamed: R26.1, TP3.1, U5.10 (PA0/*RESET/UPDI)
unnamed: SW2.3, SW2.4, U5.9 (PB0)
unnamed: TP5.1, U5.6 (TOSC1/PB3)
unnamed: TP6.1, U5.7 (TOSC2/PB2)
unnamed: C8.1, U6.4 (OUTPUT)
RED_0: LED1.3, LED9.3, LED17.3, LED25.3, R3.1
RED_1: LED5.3, LED13.3, LED21.3, LED29.3, R6.1
RED_2: LED2.3, LED10.3, LED18.3, LED26.3, R9.1
RED_3: LED6.3, LED14.3, LED22.3, LED30.3, R12.1
RED_4: LED3.3, LED11.3, LED19.3, LED27.3, R15.1
RED_5: LED7.3, LED15.3, LED23.3, LED31.3, R18.1
RED_6: LED4.3, LED12.3, LED20.3, LED28.3, R21.1
RED_7: LED8.3, LED16.3, LED24.3, LED32.3, R24.1
ROW_0: LED1.4, LED2.4, LED3.4, LED4.4, LED5.4, LED6.4, LED7.4, LED8.4, Q1.3
ROW_1: LED9.4, LED10.4, LED11.4, LED12.4, LED13.4, LED14.4, LED15.4, LED16.4, Q2.3
ROW_2: LED17.4, LED18.4, LED19.4, LED20.4, LED21.4, LED22.4, LED23.4, LED24.4, Q3.3
ROW_3: LED25.4, LED26.4, LED27.4, LED28.4, LED29.4, LED30.4, LED31.4, LED32.4, Q4.3
SHIFT_CLK: U1.11 (SH_CP), U2.11 (SH_CP), U3.11 (SH_CP), U5.12 (PA2)
S_ROW_0: Q1.1, R30.1, U5.2 (PA4)
S_ROW_1: Q2.1, R31.1, U5.3 (PA5)
S_ROW_2: Q3.1, R32.1, U5.4 (PA6)
S_ROW_3: Q4.1, R33.1, U5.5 (PA7)

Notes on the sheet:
All red current-limiting resistors set to 180Ω
All blue current-limiting resistors set to 100Ω
BLUE Shift Register
RED Shift Register
Power Distribution
All green current-limiting resistors set to 120Ω
RGB LED 8x4 Matrix
Controller
Row Multiplexer
Logic Shifting
Audio Sampling
GREEN Shift Register

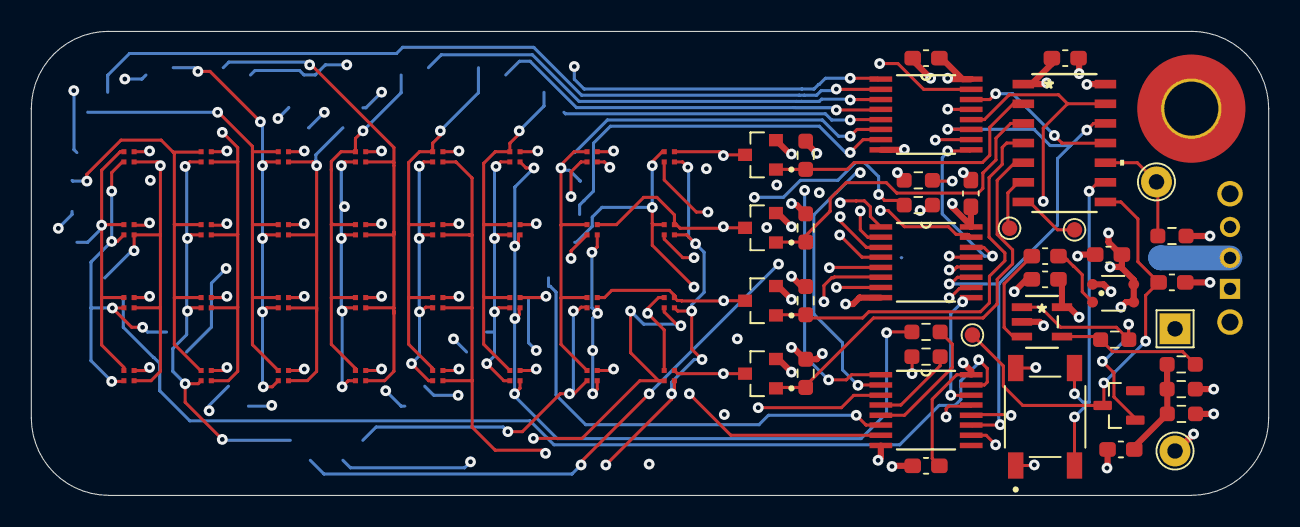
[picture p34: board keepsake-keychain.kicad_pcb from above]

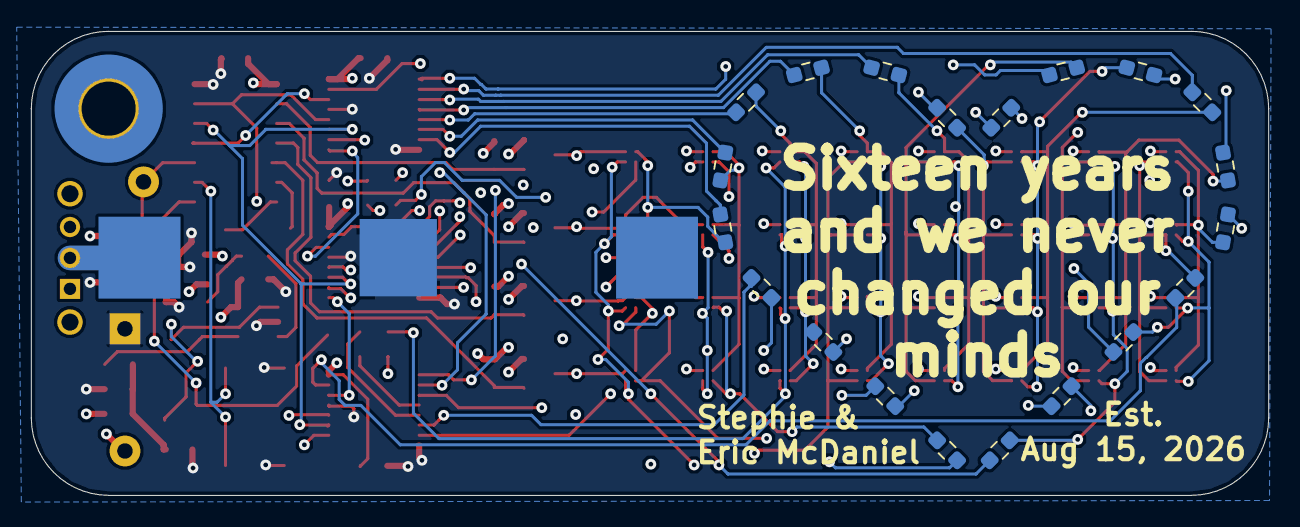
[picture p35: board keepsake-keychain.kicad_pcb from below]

Board: 4 copper layers, 80.0 x 30.0 mm, 95 parts (21 on the bottom side), 74 nets.

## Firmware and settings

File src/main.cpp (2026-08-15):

#ifdef CLEAR
#include <Arduino.h>
#include <EEPROM.h>
void setup()
{

  for (uint16_t i = 0; i < EEPROM.length(); i++)
  {
    EEPROM.update(i, 0);
  }
}
void loop() {}
#else

#include <Arduino.h>
#include "engine/engine.h"

void setup()
{
  Engine::KeychainEngine engine;
  engine.runApplication();
}

/**
 * loop() functions just as a catch block does in modern try/catch exception handling.
 * There is no game logic here.
 */
void loop()
{
  Serial.println("Keychain has encountered an unrecoverable error state.");
  delay(1000);
}
#endif

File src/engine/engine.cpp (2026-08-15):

#include "engine/engine.h"
#include "platform/configuration.h"
#include "lights/color-correction.h"
#include "utilities/logger.h"

using namespace Engine;

KeychainEngine::KeychainEngine()
{
  initializeEngine();
}

void KeychainEngine::initializeEngine()
{
  contextManager.initializeSystemMemory();

  // If debugging, ensure serial connection is stable before setting up components
#ifdef DEBUG
  Serial.begin(Platform::Configuration::serialBaud);
  while (!Serial)
  {
    delay(100);
  }
#endif

  log("Serial connection established.");
  log("Printing environment variables.");
  logf("numLeds = %u", Platform::Configuration::numLeds);
  logf("serialBaud = %u", Platform::Configuration::serialBaud);
  logf("startupSystemState = %u\n", Platform::Configuration::startupSystemState());
  log("Startup process completed. Transitioning to the first animation.");

  // immediately set PA4-7 as HIGH, the row MOSFET is active low.
  PORTA.OUTSET = PIN4_bm | PIN5_bm | PIN6_bm | PIN7_bm;

  // setup pins PA1-7 as output
  PORTA.DIRSET = PIN1_bm | PIN2_bm | PIN3_bm | PIN4_bm | PIN5_bm | PIN6_bm | PIN7_bm;

  contextManager.entropy.begin();
  contextManager.changeApplication(Platform::Configuration::startupSystemState());
}

void KeychainEngine::runApplication()
{
  while (contextManager.stateManager.isRunning())
  {
    auto &time = contextManager.time;

    time.update();
    contextManager.entropy.update(time.getMicrosecond());
    contextManager.button.update(time.getMillisecond());

    if (contextManager.button.wasHeld())
    {
      // TODO: do better than this...
      SystemState nextState = contextManager.stateManager.current() == SystemState::Animation ? SystemState::Game : SystemState::Animation;
      contextManager.changeApplication(nextState);
      continue;
    }

    if (time.getMicrosecond() - lastFullFrameRender >= frameRefreshRate)
    {
      lastFullFrameRender += frameRefreshRate;
      contextManager.application->nextEvent();
    }

    if (time.getMicrosecond() - lastMatrixRowRender >= rowRefreshRate)
    {
      lastMatrixRowRender += rowRefreshRate;
      renderFrameRow();
    }
  }
}

void KeychainEngine::renderFrameRow()
{
  disableActiveRow();
  pwmAdjustAndShiftToLeds();
  toggleLatch();
  enableActiveRow();
  selectNextMatrixRow();
  shiftBamBit();
}

inline void KeychainEngine::disableActiveRow()
{
  PORTA.OUTSET = rowMask;
}

inline void KeychainEngine::enableActiveRow()
{
  PORTA.OUTCLR = (PIN4_bm << activeRow);
}

inline void KeychainEngine::selectNextMatrixRow()
{
  activeRow = (activeRow + 1) & (Platform::Configuration::numRows - 1);
}

void KeychainEngine::pwmAdjustAndShiftToLeds()
{
  const uint8_t bamSequenceBit = (1 << bamSequence[bamBitPlane]);

  uint8_t adjustedRed = 0;
  uint8_t adjustedGreen = 0;
  uint8_t adjustedBlue = 0;

  for (uint8_t col = 0; col < Platform::Configuration::numColumns; col++)
  {
    const Lights::Color pixel = contextManager.renderer.getPixel(col, activeRow);
    // pixel = Lights::ColorCorrection::apply(pixel);

    const uint8_t r = reduceTo6Bit(pixel.r);
    const uint8_t g = reduceTo6Bit(pixel.g);
    const uint8_t b = reduceTo6Bit(pixel.b);

    /*
      Future me:
      I really want this color brightness, balance, and gamma correction to work out... but every
      microadjustment I made comes with downsides. E.g. with balance and correction both on, it creates
      an aggressive PWM flickering, enough to ruin the effect. Revisit later?

      The bit angle modulation (BAM) really might need to be reconsidered.
    */
    // const uint8_t r = Lights::LedBrightness::apply(reduceTo6Bit(pixel.r));
    // const uint8_t g = Lights::LedBrightness::apply(reduceTo6Bit(pixel.g));
    // const uint8_t b = Lights::LedBrightness::apply(reduceTo6Bit(pixel.b));

    if (r & bamSequenceBit)
    {
      adjustedRed |= (1 << col);
    }

    if (g & bamSequenceBit)
    {
      adjustedGreen |= (1 << col);
    }

    if (b & bamSequenceBit)
    {
      adjustedBlue |= (1 << col);
    }
  }

  shiftOutByte(~adjustedRed);
  shiftOutByte(~adjustedGreen);
  shiftOutByte(~adjustedBlue);
}

inline void KeychainEngine::toggleLatch()
{
  // latch high then low
  PORTA.OUTSET = PIN3_bm;
  PORTA.OUTCLR = PIN3_bm;
}

void KeychainEngine::shiftOutByte(uint8_t value)
{
  for (int8_t i = 7; i >= 0; i--)
  {
    if (value & (1 << i))
    {
      PORTA.OUTSET = PIN1_bm; // PA1 high to 74HC595 data pin
    }
    else
    {
      PORTA.OUTCLR = PIN1_bm; // PA1 (data pin) low
    }

    PORTA.OUTSET = PIN2_bm; // same format as above, PA2 high
    PORTA.OUTCLR = PIN2_bm; // PA2 low
  }
}

inline void KeychainEngine::shiftBamBit()
{
  // This is an optimization of the original implementation, which
  // used a counter increasing from 0-255, and verified the row
  // that was activated based on bit position.
  if (++bamCounter >= (1u << bamSequence[bamBitPlane]))
  {
    bamCounter = 0;
    bamBitPlane++;

    if (bamBitPlane >= 6)
    {
      bamBitPlane = 0;
    }
  }
}

/*
  This really was just a compromise to stop the BAM from flickering too much. If suppose we kept
  the 8-bit values, allowing 0-255. Values like 128 (0x80) would make a pattern of 0b10000000.
  That means for every row activation, It's on for 128 ticks, and off for the rest because of that
  bit format. If I did 170 (0xaa), then for example it's 0b10101010, which means its on for 128 ticks,
  off for 64, on for 32 more, off for 16, ... and so on. That feels continuous to human eyes (at least
  mines). But the 128 on, 128 off, you can clearly see the PWM pulsing. This function was a compromise.
  I reduced the PWM flickering, but at the expense of reduced the color depth and bit-rate. Thanks for
  coming to my Ted talk.
*/
uint8_t KeychainEngine::reduceTo6Bit(uint8_t value)
{
  return value >> 2;
}

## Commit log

2026-06-06 Add CR 2032 coin battery holder
    [BAT-HLD-003-SMT.step, keepsake-keychain.kicad_pcb, keepsake-keychain.kicad_sch]
2026-06-06 Add SPDT switch
    [SLW-129956-4A-RA-N-D.step, keepsake-keychain.kicad_sch]
2026-06-06 Add RGB LED
    [SMD4_UHD111A-FKA_CRW.step]
2026-06-06 Add 74HC595 shift register to lib
    [74HC595PW_118.step, keepsake-keychain.kicad_sch]
2026-06-06 Add ATtiny1614 IC
    [SOIC14_SL_MCH.step, keepsake-keychain.kicad_sch]
2026-06-06 Restructure component library
    [74hc595.step, BAT-HLD-003-SMT.step, attiny-1614.step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]
2026-06-06 Add P-channel MOSFET
    [keepsake-keychain.kicad_pcb, keepsake-keychain.kicad_sch, mosfet.step]
2026-06-08 Add pin for UPDI programming
    [keepsake-keychain.kicad_sch]
2026-06-08 Add tactile push button
    [keepsake-keychain.kicad_sch]
2026-06-08 Connect MOSFETs, add MEMS microphone
    [keepsake-keychain.kicad_sch, microphone.step]
2026-06-09 Add op-amp
    [bat54.step, keepsake-keychain.kicad_sch, op-amp.step]
2026-06-09 Add filtering and label nets
    [keepsake-keychain.kicad_sch]
2026-06-09 Continue schematic stweaks, connect nets
    [keepsake-keychain.kicad_sch]
2026-06-10 Replace tactile button and power switch for space conservancy
    [keepsake-keychain.kicad_sch, spdt-switch.step, tactile-push-button.step]
2026-06-10 Upgrade CR2032 to CR2450 for longer battery life
    [coin-battery-holder.step, keepsake-keychain.kicad_sch]
2026-06-10 Assign footprints to components
    [keepsake-keychain.kicad_pcb, keepsake-keychain.kicad_sch]
2026-06-10 Swap push button and slide switch for better options
    [keepsake-keychain.kicad_pcb, keepsake-keychain.kicad_sch, spdt-switch.step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]
2026-06-11 Attach models. Complete schematic, pass ERC.
    [keepsake-keychain.kicad_pcb, keepsake-keychain.kicad_sch]
2026-06-11 Place LED passives in line
    [keepsake-keychain.kicad_pcb, keepsake-keychain.kicad_sch]
2026-06-12 Rename nets, move resistors to rear
    [keepsake-keychain.kicad_pcb, keepsake-keychain.kicad_sch]
2026-06-12 Finish heart, refine references designator positions
    [keepsake-keychain.kicad_pcb]
2026-06-13 Fix broken net, fix via annular ring constraint
    [keepsake-keychain.kicad_pcb, keepsake-keychain.kicad_sch]
2026-06-13 Place remaining passives
    [keepsake-keychain.kicad_pcb, keepsake-keychain.kicad_sch]
2026-06-14 Fix errors from unassigned pins
    [keepsake-keychain.kicad_pcb, keepsake-keychain.kicad_sch]
2026-06-14 Replace tactile push button for stable, lower profile
    [keepsake-keychain.kicad_pcb, keepsake-keychain.kicad_sch, tactile-push-button.step]
2026-06-14 Route all traces for controller
    [keepsake-keychain.kicad_pcb, keepsake-keychain.kicad_sch]
2026-06-14 Route first half of LED traces
    [keepsake-keychain.kicad_pcb, keepsake-keychain.kicad_sch]
2026-06-15 Convert to four-layer board (sigh)
    [keepsake-keychain.kicad_pcb]
2026-06-16 Finish routing traces, export BOM and images
    [keepsake-keychain.csv]
2026-06-16 Clean BOM, export gerbers
    [keepsake-keychain-B_Adhesive.gbr, keepsake-keychain-B_Cu.gbr, keepsake-keychain-B_Fab.gbr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]
2026-06-17 Tweak layout for additional GND pour
    [keepsake-keychain.kicad_pcb]
2026-06-18 Final export, release for pcbway
    [keepsake-keychain-B_Adhesive.gbr, keepsake-keychain-B_Cu.gbr, keepsake-keychain-B_Fab.gbr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]
2026-07-14 Add SystemState and startup routine
    [configuration.h]
2026-07-15 Successful flash to board, setup UART
2026-07-16 Add light/color definitions. Resolve compilation issues
    [engine.cpp]
2026-07-16 Establish colors, buffer, matrix, and luminance
    [configuration.h]
2026-07-16 Direct bit manipulations, control display
    [configuration.h]
2026-07-17 Correct dimness issue, fix activation timing
    [engine.cpp]
2026-07-17 Clean PWM
2026-07-19 Complete engine renderer
    [configuration.h]
2026-07-20 Implement button and event handlers
    [configuration.h]
2026-07-20 Troubleshoot setup issues, tune timers
    [configuration.h]
2026-07-21 Complete button mapping, navigate menu options
2026-07-21 Read next LED from buffer, remove test fixture
    [engine.cpp]
2026-07-21 Expand Renderer public API
    [configuration.h]
2026-07-22 Remove Luminance, dead code, set gamma lookup
    [configuration.h]
2026-07-22 Provide complete Renderer public API
    [configuration.h]
2026-07-23 Fix pointer vs reference mistake
    [engine.cpp, entropy.cpp]
2026-07-24 Change sign standard, use sign to allow negative position out of frame
    [configuration.h]
2026-07-27 Refactor background and button logic
2026-07-28 Additional cleanup, add reset.
    [button.cpp, button.h]
2026-07-30 Fix bug in button missing activations
    [button.cpp, button.h]
2026-07-30 Organize structure, add enclosure outline
    [74hc595.step, attiny-1614.step, bat54.step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]
2026-07-31 Add slot for grip
    [wedding-keychain.FCStd]
2026-08-01 Expand width
    [wedding-keychain.FCStd]
2026-08-02 Adjust edge and height after first print
    [wedding-keychain.FCStd]
2026-08-02 Add lid with slide rail
    [wedding-keychain.FCStd]
2026-08-02 Adjust lid size for better closure
    [wedding-keychain.FCStd]
2026-08-03 Additional print and adjustment
    [wedding-keychain-enclosure.3mf, wedding-keychain-lid.3mf, wedding-keychain.FCStd]
2026-08-04 Tighten rails, move snap fit to end rather than start
    [wedding-keychain-enclosure.3mf, wedding-keychain-lid.3mf, wedding-keychain.FCStd]
2026-08-04 Fix overtightened rail
    [wedding-keychain-enclosure.3mf, wedding-keychain-lid.3mf, wedding-keychain.FCStd]
2026-08-04 Reverse offset direction
    [wedding-keychain-enclosure.3mf, wedding-keychain-lid.3mf, wedding-keychain.FCStd]
2026-08-04 Microadjust rail shape. Clean, successful print
    [wedding-keychain-lid.3mf, wedding-keychain.FCStd]
2026-08-05 Add personalization text
    [wedding-keychain-combo.3mf, wedding-keychain-enclosure.3mf, wedding-keychain-lid.3mf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]
2026-08-05 Create parts diagram for instructions, widen CAD thumb opening
    [wedding-keychain-combo.3mf, wedding-keychain-enclosure.3mf]
2026-08-06 Minor text revision, clean up
    [wedding-keychain-combo.3mf, wedding-keychain-enclosure.3mf]
2026-08-07 Restore missing knurling
    [wedding-keychain-lid.3mf]
2026-08-14 Remove alternating background texture, auto level inc
    [wedding-keychain-enclosure.3mf]
2026-08-14 Retain last used game/animation on startup
    [configuration.h]
